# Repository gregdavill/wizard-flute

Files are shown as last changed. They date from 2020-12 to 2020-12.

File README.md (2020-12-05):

# Wizard Flute #

     ~ Current Status: Prototype boards ordered ~
     
     Note: This design was performed in KiCad nightly , you will need a Nightly build to open and edit these source files.

## What is it?

ESP32-S2 + LED Display

A Compact 4 digit 7-segment clock display with an ESP32-S2 control board.

It is powered off a USB-C connection on the side of the unit, and features 1 button.

This design will become a desk clock that sets it's time from your local WiFi using NTP.

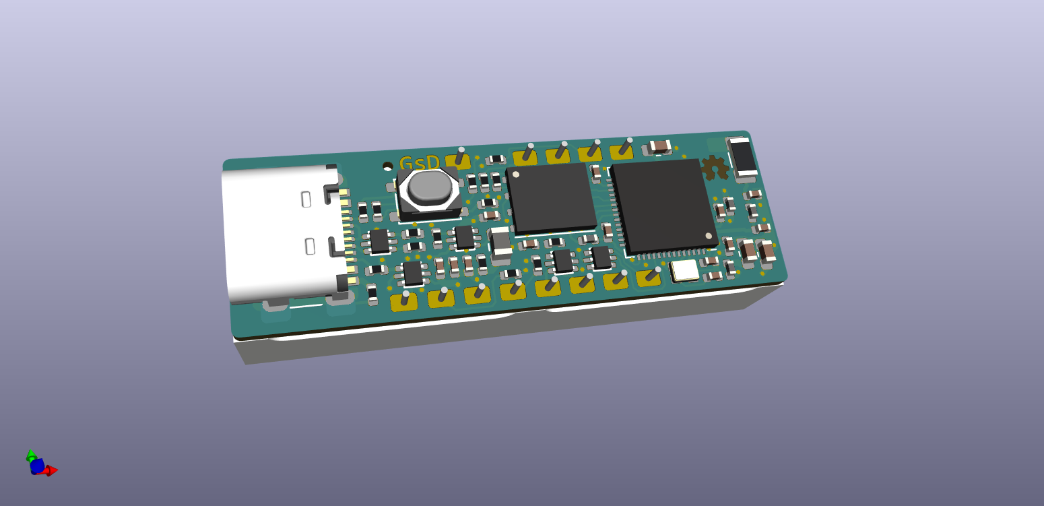
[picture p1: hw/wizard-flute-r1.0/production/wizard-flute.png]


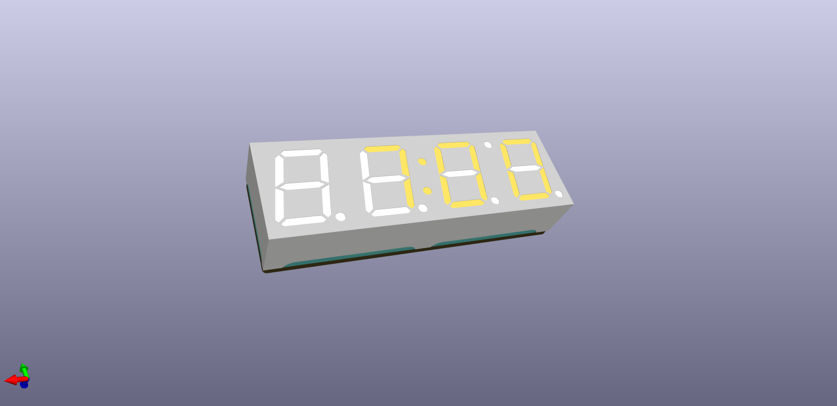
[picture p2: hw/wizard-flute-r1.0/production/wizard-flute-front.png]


## Licence
 * Hardware in this repository is licensed under CERN-OHL-P

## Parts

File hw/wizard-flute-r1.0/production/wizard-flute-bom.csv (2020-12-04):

Item | Qty | Reference(s) | Value | LibPart | Footprint | Datasheet | Mfg | PN | Source | Tol
1 | 1 | AE1 | Antenna | Device:Antenna_Shield | led-clock:Ant_3216 | ~ | Sunlord | SLDA31-2R400G-S2TF
2 | 1 | C1 | 4.7uF | Device:C | Capacitor_SMD:C_0402_1005Metric | ~ | Yageo | CC0402KRX5R6BB475
3 | 1 | C2 | 2.2uF | icebreaker-bitsy-rescue:pkl_C_Small-pkl_device | Capacitor_SMD:C_0402_1005Metric |  | Yageo | CC0402MRX5R5BB225
4 | 2 | C3, C4 | 18pF | icebreaker-bitsy-rescue:pkl_C_Small-pkl_device | Capacitor_SMD:C_0402_1005Metric |  | Yageo | CC0402GRNPO9BN180
5 | 1 | C5 | 6.8pF | Device:C | Capacitor_SMD:C_0402_1005Metric | ~ | Yageo | CC0402CRNPO9BN6R8
6 | 1 | C6 | 1uF | Device:C | Capacitor_SMD:C_0402_1005Metric | ~ | Yageo | CC0402KRX5R6BB105
7 | 1 | C7 | 2.2uF | Device:C | Capacitor_SMD:C_0402_1005Metric | ~ | Yageo | CC0402MRX5R5BB225
8 | 3 | C8, C14, C19 | 10u | icebreaker-bitsy-rescue:pkl_C-pkl_device | Capacitor_SMD:C_0603_1608Metric |  | Yageo | CC0603KRX5R5BB106
9 | 4 | C9, C12, C13, C15 | 100n | icebreaker-bitsy-rescue:pkl_C_Small-pkl_device | Capacitor_SMD:C_0402_1005Metric |  | Yageo | CC0402ZRY5V7BB104
10 | 2 | C10, C11 | TBD | icebreaker-bitsy-rescue:pkl_C_Small-pkl_device | Capacitor_SMD:C_0402_1005Metric |  |  |  | ANY
11 | 3 | FB1, FB2, FB3 | 240R | Device:Ferrite_Bead_Small | Inductor_SMD:L_0402_1005Metric | ~ | Murata Electronics | BLM15BC241SN1D
12 | 1 | J1 | USB_C | Connector:USB_C_Receptacle_USB2.0 | pkl_connectors:USB_C_Receptacle_HRO_TYPE-C-31-M-12 | https://www.usb.org/sites/default/files/documents/usb_type-c.zip | GCT | USB4105-GF-A
13 | 1 | L1 | 2.2uH | Device:L_Small | Inductor_SMD:L_0805_2012Metric | ~ | Sunltech Tech | SLM20122R2MIT
14 | 1 | L2 | TBD | Device:L_Small | Inductor_SMD:L_0402_1005Metric | ~
15 | 1 | LE1 | KEM-3942-AY | led-clock:KEM-3942-AY | led-clock:kem-3942-ay
16 | 3 | Q1, Q2, Q3 | Q_DUAL_NMOS_S1G1D2S2G2D1 | Device:Q_DUAL_NMOS_S1G1D2S2G2D1 | led-clock:SOT-666 | ~ | ROHM Semicon | EM6K7T2R
17 | 1 | R1 | 1M | icebreaker-bitsy-rescue:pkl_R_Small-pkl_device | Resistor_SMD:R_0402_1005Metric |  | Yageo | RC0402FR-071ML
18 | 2 | R2, R3 | 5k1 | icebreaker-bitsy-rescue:pkl_R_Small-pkl_device | Resistor_SMD:R_0402_1005Metric |  | Yageo | RC0402FR-075K1L
19 | 2 | R4, R5 | 22E | icebreaker-bitsy-rescue:pkl_R_Small-pkl_device | Resistor_SMD:R_0402_1005Metric |  | Yageo | RC0402FR-0722RL
20 | 1 | R6 | 210k | Device:R | Resistor_SMD:R_0402_1005Metric | ~ | Yageo | RC0402FR-07210KL |  | 1%
21 | 1 | R7 | 47k | Device:R | Resistor_SMD:R_0402_1005Metric | ~ | Yageo | RC0402FR-0747KL
22 | 8 | R8, R9, R11, R12, R13, R14, R15, R16 | 220R | icebreaker-bitsy-rescue:pkl_R_Small-pkl_device | Resistor_SMD:R_0402_1005Metric |  | Yageo | RC0402FR-0722RL
23 | 1 | R10 | 10k | icebreaker-bitsy-rescue:pkl_R_Small-pkl_device | Resistor_SMD:R_0402_1005Metric |  | Yageo | RC0402FR-0710KL
24 | 1 | SW1 | TACT | icebreaker-bitsy-rescue:TACT-pkl_misc | pkl_buttons_switches:SW_SPST_3x4x2.5
25 | 1 | U1 | USBLC6-2 | icebreaker-bitsy-rescue:USBLC6-2-pkl_misc | led-clock:SOT-666 |  | STMicroelectronics | USBLC6-2P6
26 | 1 | U2 | TLV62569DRL | Regulator_Switching:TLV62569DRL | led-clock:SOT-666 | http://www.ti.com/lit/ds/symlink/tlv62569.pdf | Texas Instruments | TLV62569DRLR
27 | 1 | U3 | ESP32-S2 | obsidian-boa:ESP32-S2 | Package_DFN_QFN:QFN-56-1EP_7x7mm_P0.4mm_EP5.6x5.6mm |  | Espressif Systems | ESP32-S2
28 | 1 | U4 | W25Q32JVZPIQ | Memory_Flash:W25Q32JVSS | Package_SON:WSON-8-1EP_6x5mm_P1.27mm_EP3.4x4mm | http://www.winbond.com/resource-files/w25q32jv%20revg%2003272018%20plus.pdf | Winbond Electronics | W25Q32JVZPIQ
29 | 1 | Y1 | 40MHz | Device:Crystal_GND24_Small | led-clock:Crystal_SMD_4Pin_2.0x1.6mm | ~ | TKD | SX20Y040000BC1T

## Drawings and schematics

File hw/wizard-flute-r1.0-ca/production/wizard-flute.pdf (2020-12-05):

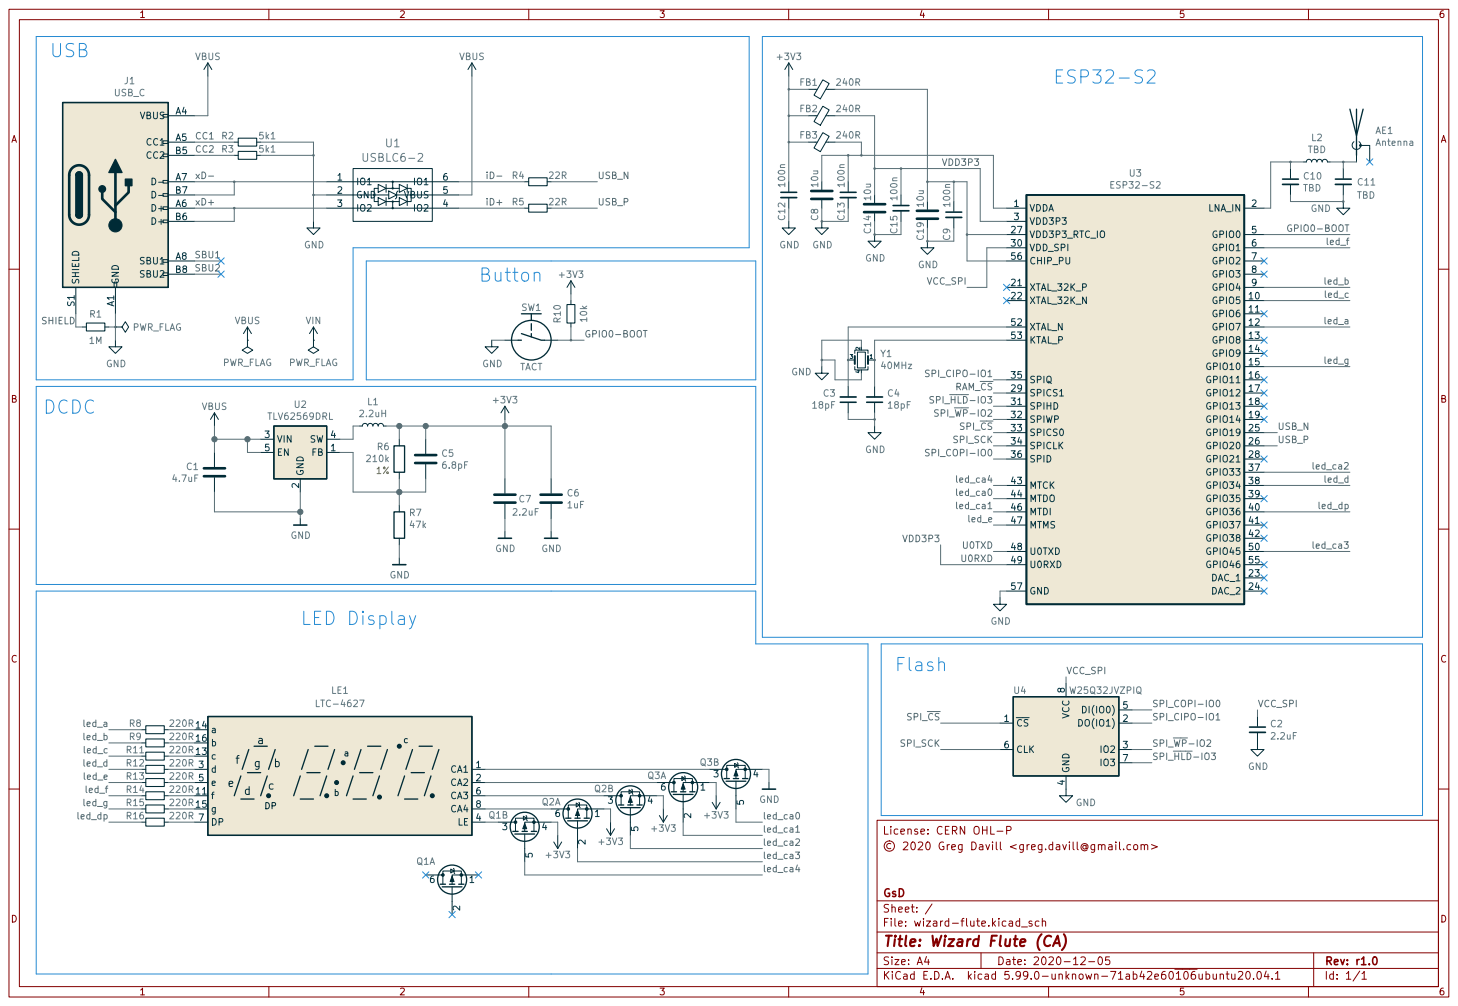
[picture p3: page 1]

xD+ | IO2 3 | IO2 | 4 VBUS 5

2 VIN 3 SW 4 EN 5 U2 TLV62569DRL GND

File: wizard-flute.kicad_sch Sheet: / GsD

Id: 1/1 Title: Wizard Flute (CA)

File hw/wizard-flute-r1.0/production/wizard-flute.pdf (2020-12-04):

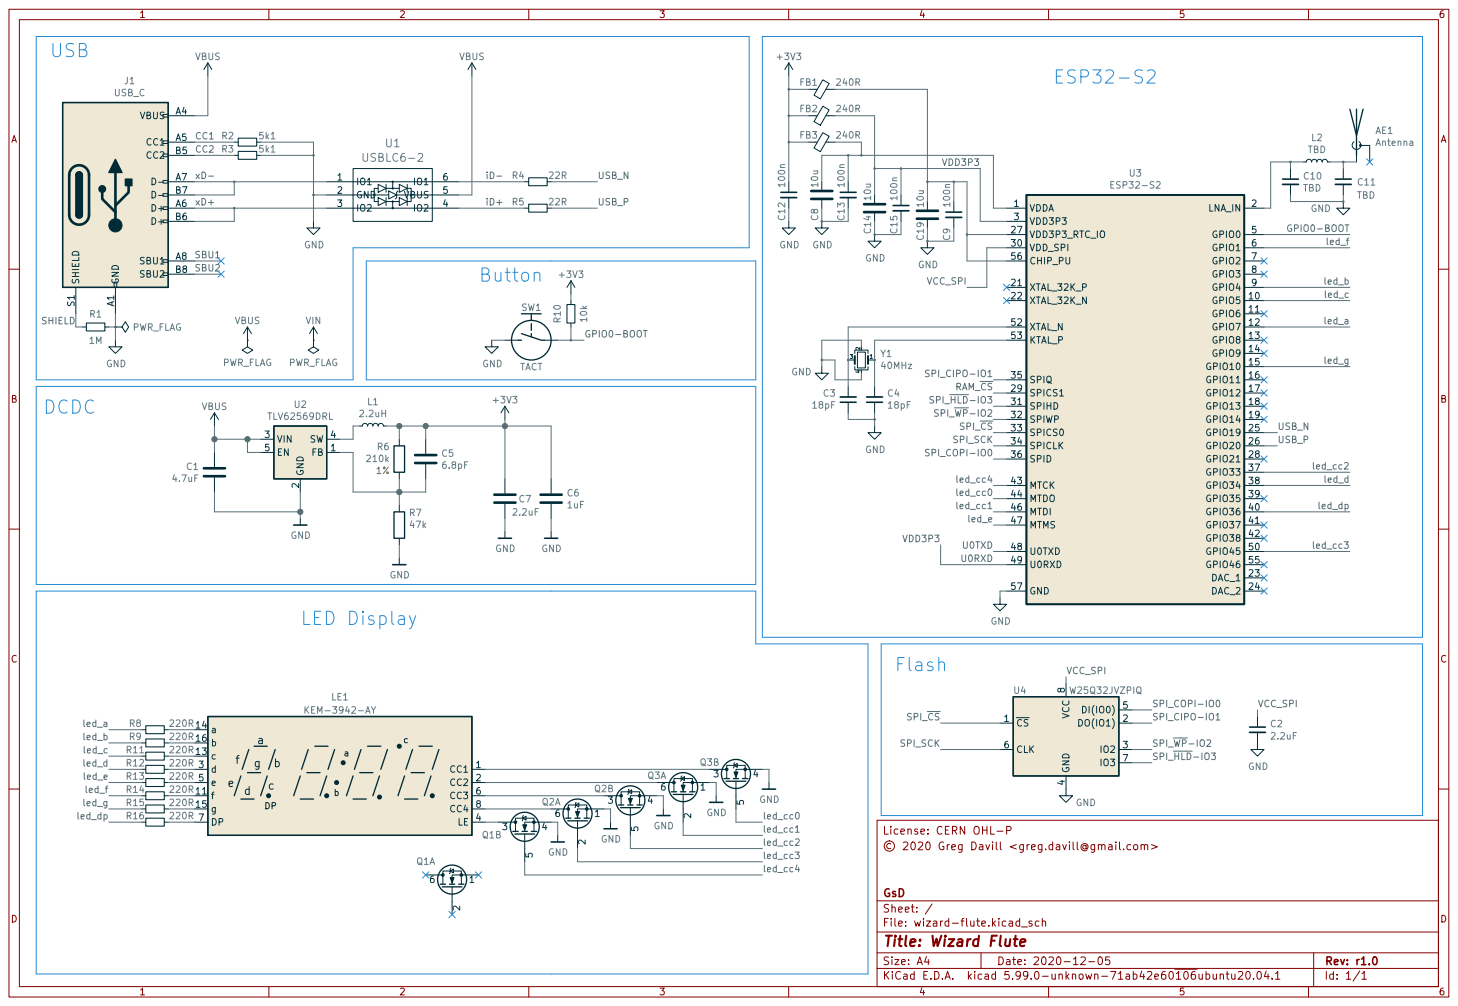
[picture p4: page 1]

File: wizard-flute.kicad_sch Sheet: / GsD

Id: 1/1 Title: Wizard Flute

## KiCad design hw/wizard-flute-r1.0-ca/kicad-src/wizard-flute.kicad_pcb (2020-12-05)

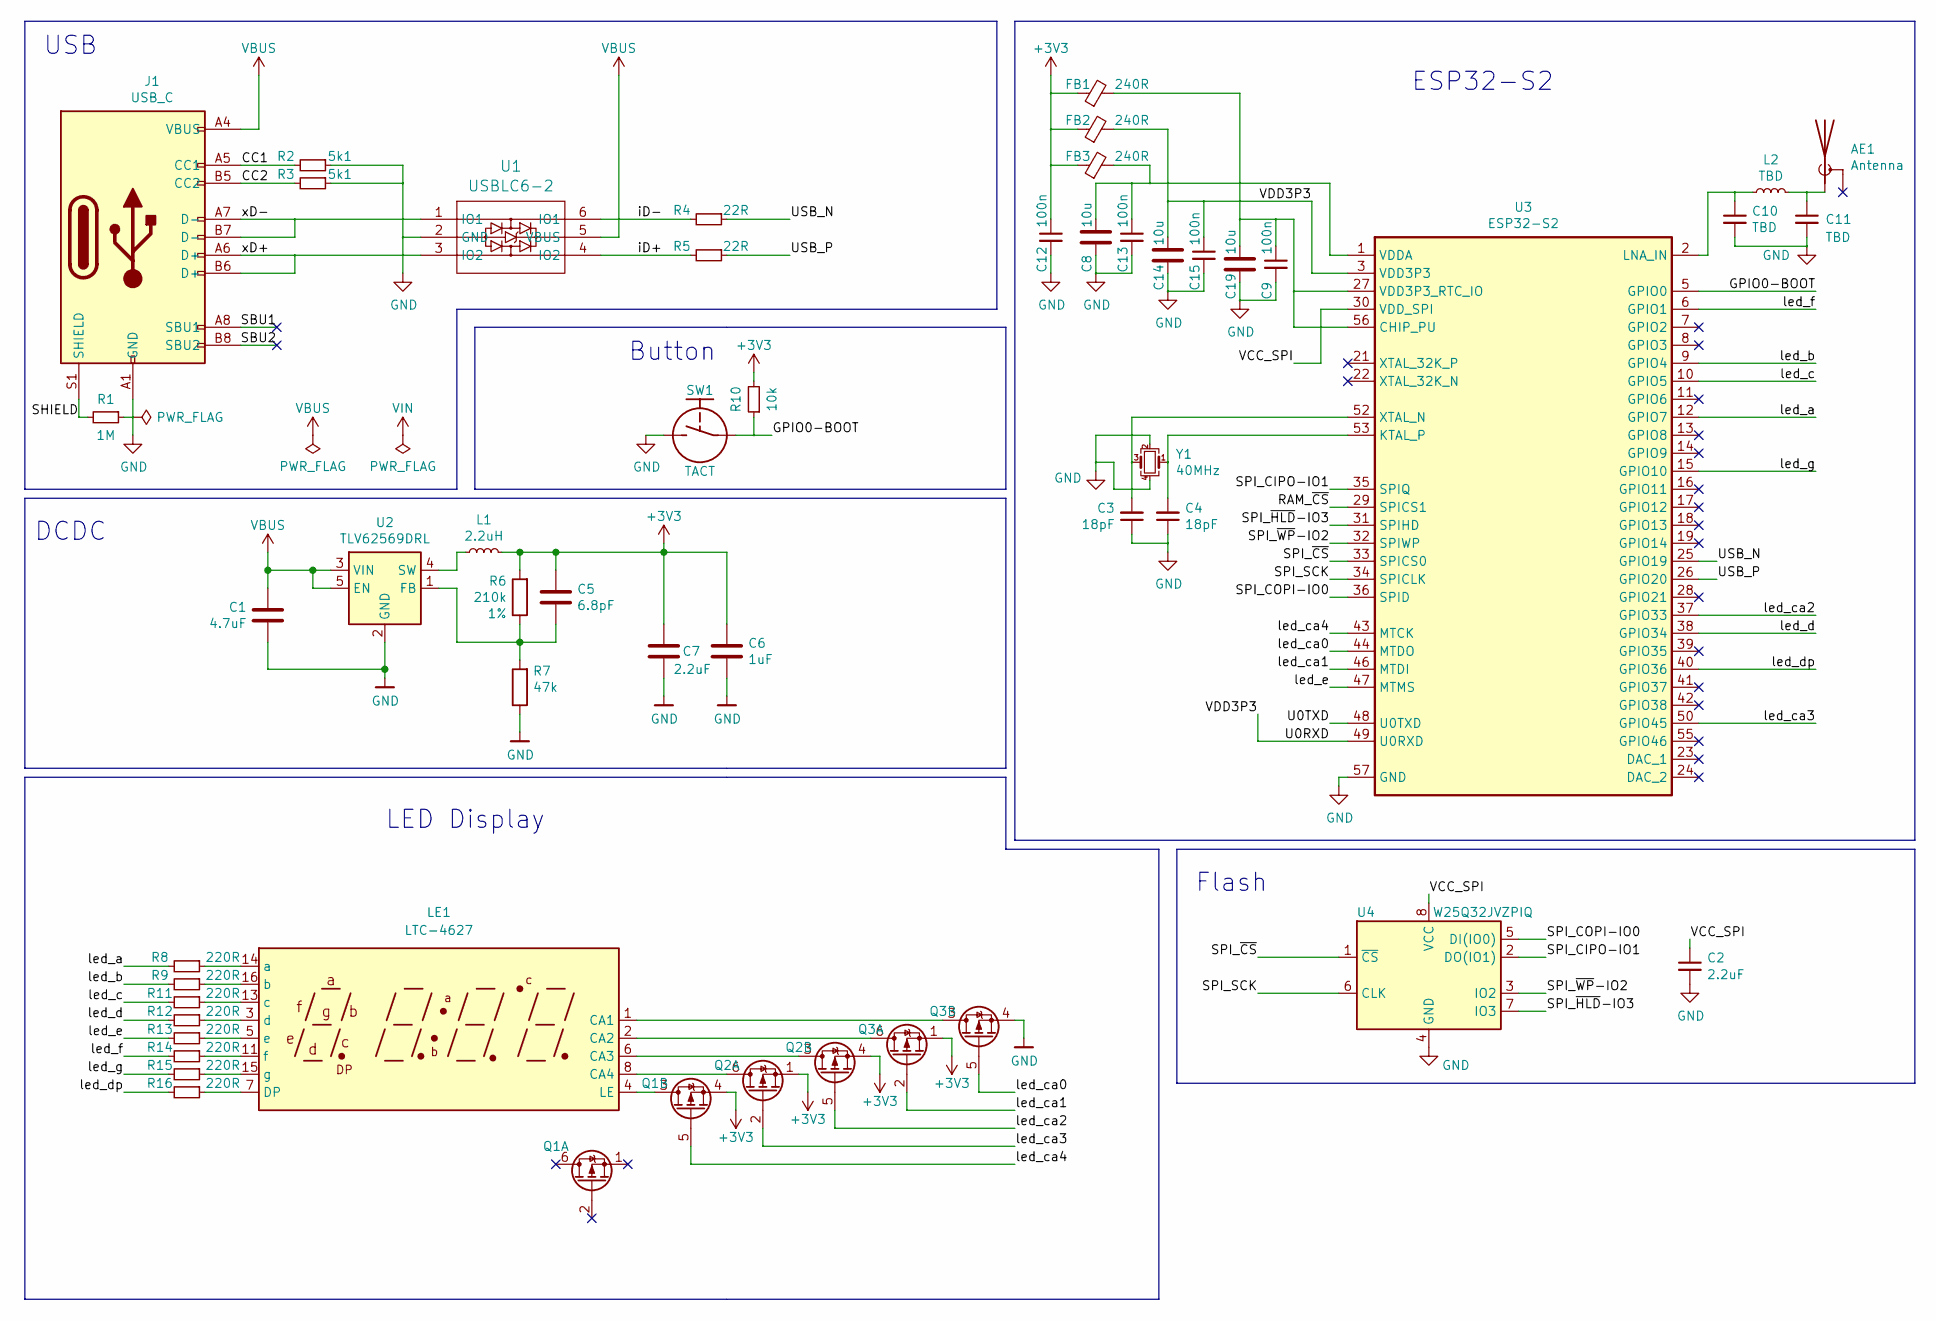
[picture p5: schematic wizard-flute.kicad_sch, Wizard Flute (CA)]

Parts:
AE1: Antenna; Ant_3216
C1: 4.7uF; C_0402_1005Metric
C2, C7: 2.2uF; C_0402_1005Metric
C3, C4: 18pF; C_0402_1005Metric
C5: 6.8pF; C_0402_1005Metric
C6: 1uF; C_0402_1005Metric
C8, C14, C19: 10u; C_0603_1608Metric
C9, C12, C13, C15: 100n; C_0402_1005Metric
C10, C11: TBD; C_0402_1005Metric
FB1, FB2, FB3: 240R; L_0402_1005Metric
J1: USB_C; USB_C_Receptacle_HRO_TYPE-C-31-M-12
L1: 2.2uH; L_0805_2012Metric
L2: TBD; L_0402_1005Metric
LE1: LTC-4627; kem-3942-ay
Q1, Q2, Q3: NTZD3152P; SOT-666
R1: 1M; R_0402_1005Metric
R2, R3: 5k1; R_0402_1005Metric
R4, R5: 22R; R_0402_1005Metric
R6: 210k; R_0402_1005Metric
R7: 47k; R_0402_1005Metric
R8, R9, R11, R12, R13, R14, R15, R16: 220R; R_0402_1005Metric
R10: 10k; R_0402_1005Metric
SW1: TACT; SW_SPST_3x4x2.5
U1: USBLC6-2; SOT-666
U2: TLV62569DRL; SOT-666
U3: ESP32-S2; QFN-56-1EP_7x7mm_P0.4mm_EP5.6x5.6mm
U4: W25Q32JVZPIQ; WSON-8-1EP_6x5mm_P1.27mm_EP3.4x4mm
Y1: 40MHz; Crystal_SMD_4Pin_2.0x1.6mm

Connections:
+3V3: C5.1, C6.1, C7.1, C12.1, FB1.1, FB2.1, FB3.1, L1.2, Q1.4 (S), Q2.1 (S), Q2.4 (S), Q3.1 (S), R6.2, R10.2
/CC1: J1.A5 (CC1), R2.2
/CC2: J1.B5 (CC2), R3.2
/GPIO0-BOOT: R10.1, SW1.1, U3.5 (GPIO0)
/RAM_~CS: U3.29 (SPICS1)
/SBU1: J1.A8 (SBU1)
/SBU2: J1.B8 (SBU2)
/SHIELD: J1.S1 (SHIELD), R1.2
/SPI_CIPO-IO1: U3.35 (SPIQ), U4.2 (DO(IO1))
/SPI_COPI-IO0: U3.36 (SPID), U4.5 (DI(IO0))
/SPI_SCK: U3.34 (SPICLK), U4.6 (CLK)
/SPI_~CS: U3.33 (SPICS0), U4.1 (~CS)
/SPI_~HLD~-IO3: U3.31 (SPIHD), U4.7 (IO3)
/SPI_~WP~-IO2: U3.32 (SPIWP), U4.3 (IO2)
/U0RXD: C14.1, C15.1, FB2.2, U3.3 (VDD3P3), U3.4 (VDD3P3), U3.49 (U0RXD)
/U0TXD: U3.48 (U0TXD)
/USB_N: R4.1, U3.25 (GPIO19)
/USB_P: R5.1, U3.26 (GPIO20)
/VCC_SPI: C2.1, U3.30 (VDD_SPI), U4.8 (VCC)
/iD+: R5.2, U1.4 (IO2)
/iD-: R4.2, U1.6 (IO1)
/led_a: R8.2, U3.12 (GPIO7)
/led_b: R9.2, U3.9 (GPIO4)
/led_c: R11.2, U3.10 (GPIO5)
/led_ca0: Q3.5 (G), U3.44 (MTDO)
/led_ca1: Q3.2 (G), U3.46 (MTDI)
/led_ca2: Q2.5 (G), U3.37 (GPIO33)
/led_ca3: Q2.2 (G), U3.50 (GPIO45)
/led_ca4: Q1.5 (G), U3.43 (MTCK)
/led_d: R12.2, U3.38 (GPIO34)
/led_dp: R16.2, U3.40 (GPIO36)
/led_e: R13.2, U3.47 (MTMS)
/led_f: R14.2, U3.6 (GPIO1)
/led_g: R15.2, U3.15 (GPIO10)
/xD+: J1.A6 (D+), J1.B6 (D+), U1.3 (IO2)
/xD-: J1.A7 (D-), J1.B7 (D-), U1.1 (IO1)
GND: C1.2, C2.2, C3.1, C4.1, C6.2, C7.2, C8.2, C9.2, C10.2, C11.2, C12.2, C13.2, C14.2, C15.2, C19.2, J1.A1 (GND), J1.A12 (GND), J1.B1 (GND), J1.B12 (GND), Q3.4 (S), R1.1, R2.1, R3.1, R7.1, SW1.2, U1.2 (GND), U2.2 (GND), U3.57 (GND), U4.4 (GND), Y1.2, Y1.4
unnamed: AE1.1 (A), C11.1, L2.2
unnamed: C3.2, U3.52 (XTAL_N), Y1.3
unnamed: C4.2, U3.53 (KTAL_P), Y1.1
unnamed: C5.2, R6.1, R7.2, U2.1 (FB)
unnamed: C10.1, L2.1, U3.2 (LNA_IN)
unnamed: C8.1, C13.1, FB3.2, U3.1 (VDDA), U3.51 (VDDA), U3.54 (VDDA)
unnamed: C9.1, C19.1, FB1.2, U3.20 (VDD3P3_RTC), U3.27 (VDD3P3_RTC_IO), U3.45 (VDD3P3_CPU), U3.56 (CHIP_PU)
unnamed: L1.1, U2.4 (SW)
unnamed: LE1.1 (CA1), Q3.3 (D)
unnamed: LE1.2 (CA2), Q3.6 (D)
unnamed: LE1.4 (LE), Q1.3 (D)
unnamed: LE1.6 (CA3), Q2.3 (D)
unnamed: LE1.8 (CA4), Q2.6 (D)
unnamed: LE1.14 (a), R8.1
unnamed: LE1.16 (b), R9.1
unnamed: LE1.13 (c), R11.1
unnamed: LE1.3 (d), R12.1
unnamed: LE1.5 (e), R13.1
unnamed: LE1.11 (f), R14.1
unnamed: LE1.15 (g), R15.1
unnamed: LE1.7 (DP), R16.1
VBUS: C1.1, J1.A4 (VBUS), J1.A9 (VBUS), J1.B4 (VBUS), J1.B9 (VBUS), U1.5 (VBUS), U2.3 (VIN), U2.5 (EN)

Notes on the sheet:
DCDC
USB
LED Display
Button
Flash
ESP32-S2

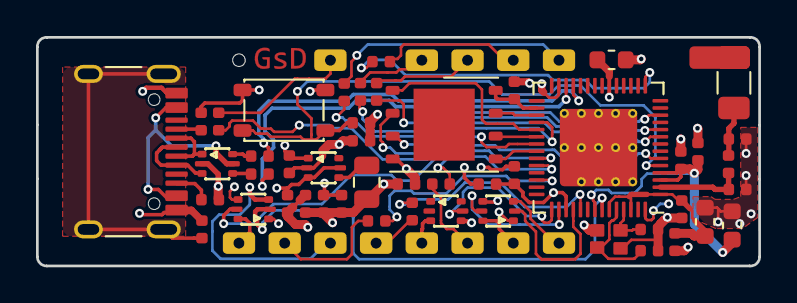
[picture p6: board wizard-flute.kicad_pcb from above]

Board: 4 copper layers, 40.1 x 12.7 mm, 49 parts (1 on the bottom side), 55 nets.

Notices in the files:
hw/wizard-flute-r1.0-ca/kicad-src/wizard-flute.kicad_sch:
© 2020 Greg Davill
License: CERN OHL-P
